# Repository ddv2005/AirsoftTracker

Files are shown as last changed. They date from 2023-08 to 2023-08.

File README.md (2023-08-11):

# AirsoftTracker

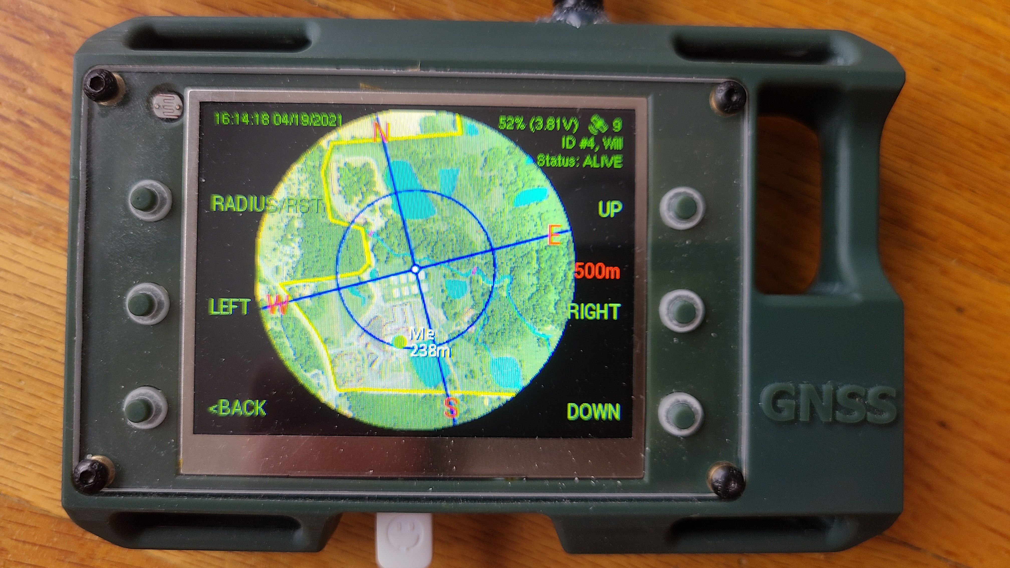
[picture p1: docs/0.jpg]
Airsoft Tracker


Airsoft tracker based on ESP32 with GPS and Lora.
Main features:
- GPS based tracking
- Support basic maps with zoom and rotation
- Lora based communication with P2P
- IMU 9250 for directions
- Current player status
- Timers

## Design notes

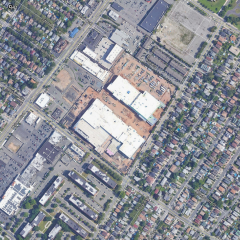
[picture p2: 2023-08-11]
screens/mainscreen/images/0_Converted.png

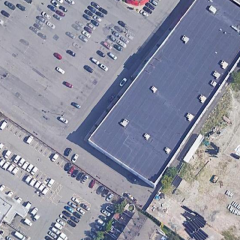
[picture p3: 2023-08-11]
screens/mainscreen/images/Untitled-2_Converted.png

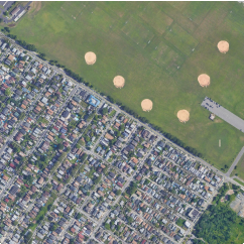
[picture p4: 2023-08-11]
screens/ms2/images/Untitled-2_converted.png

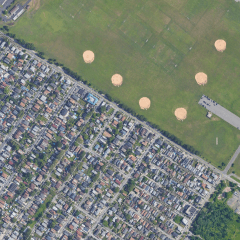
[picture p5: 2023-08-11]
screens/ms2/images/Untitled-2-fs8.png

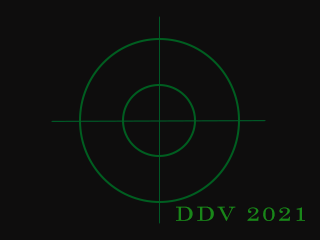
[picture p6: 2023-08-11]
images/at.png

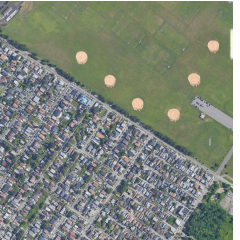
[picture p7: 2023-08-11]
screens/mainscreen/images/Untitled-2-fs8.png

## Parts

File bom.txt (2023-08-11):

1. LILYGO® TTGO T-Beam V1.1 SX1262 LORA 915MHZ ESP32 WiFi Wireless Bluetooth Module GPS NEO-M8N IPEX 18650 $41.85
https://www.aliexpress.com/item/4001287221970.html?spm=a2g0s.9042311.0.0.1f854c4dBQY7TG

2. EVE3-35A-IPS-BLH-TPN-F128 $64.5
https://www.matrixorbital.com/eve3-35a-ips

3. MCP23017 $13
https://www.aliexpress.com/item/32957655097.html?spm=a2g0s.9042311.0.0.1f854c4dBQY7TG

4. SGY-9250 $9 
https://www.aliexpress.com/item/1904051617.html?spm=a2g0s.9042311.0.0.1f854c4dBQY7TG

5. 76342-303LF x2  $2  or      CES-103-01-G-D 
https://www.newark.com/amphenol-icc/76342-303lf/connector-rcpt-6pos-2row-2-54mm/dp/62K8357

6. B3S-1000P x6 $2
https://www.newark.com/omron-electronic-components/b3s-1000p/switch-tactile-spst-no-50ma-smd/dp/50B6363

7. MOLEX 15134-0800 $2.5
https://www.newark.com/molex/15134-0800/cable-assy-8pos-rcpt-rcpt-2/dp/33AC8053

8. MOLEX 53048-0810 $1
https://www.newark.com/molex/53048-0810/connector-header-8pos-1row-1-25mm/dp/98K9836

9. SPC20493 or XG8T-0631 x2 $1
https://www.newark.com/multicomp/spc20493/board-board-connector-header-6way/dp/93K5746
https://www.newark.com/omron-electronic-components/xg8t-0631/connector-header-6-position-2row/dp/05M2064

10. S2B-PH-SM4-TB(LF)(SN)  $0.8
https://www.newark.com/jst-japan-solderless-terminals/s2b-ph-sm4-tb-lf-sn/wire-to-board-connector-header/dp/38K8067

11. GM5539 5mm $0.5
https://www.amazon.com/gp/product/B01N7V536K/ref=ppx_yo_dt_b_search_asin_title?ie=UTF8&psc=1

12. Optional DWM1000 $21
https://www.mouser.com/ProductDetail/772-DWM1000/

13. 10mmx2mm Mini Tiny Vibration Motors 10000rpm Flat Coin Button-Type Micro DC Vibrating Motor $1
https://www.amazon.com/gp/product/B073YFR5WR/ref=ppx_yo_dt_b_search_asin_title?ie=UTF8&psc=1

14. HTSW-150-06-G-S
https://www.digikey.com/en/products/detail/samtec-inc/HTSW-150-06-G-S/8085307

15. Adafruit NPN Bipolar Transistors (PN2222) 
https://www.amazon.com/gp/product/B00XW2OK7M/ref=ppx_yo_dt_b_search_asin_title?ie=UTF8&psc=1

case+hw $10
glass $3
pcb $3

$133/153

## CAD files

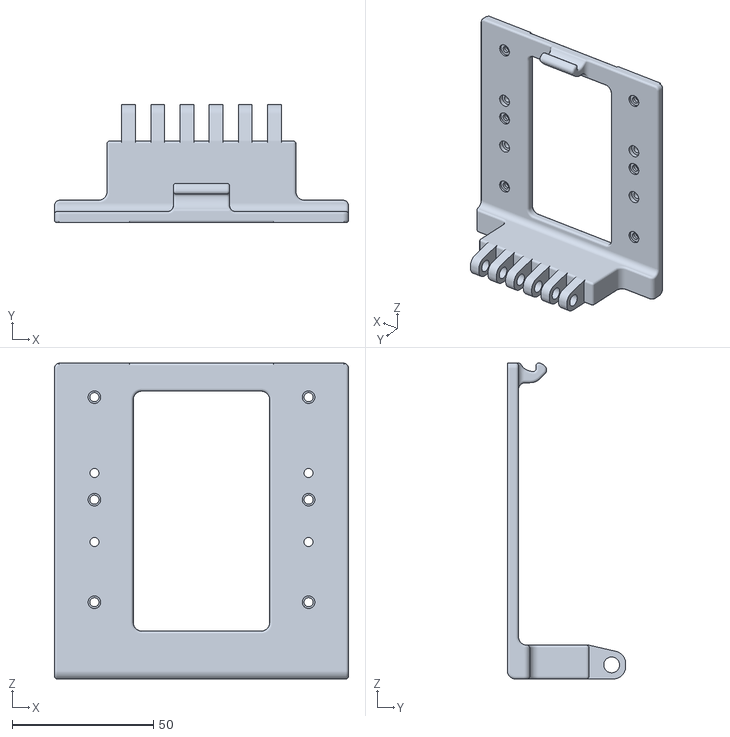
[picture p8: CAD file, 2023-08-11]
cases/holder.stl
104.3 x 42.0 x 112.0

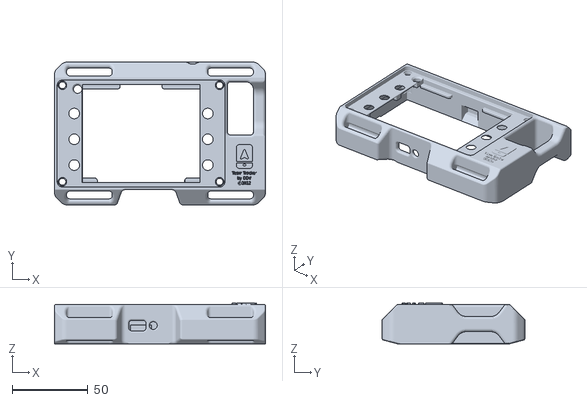
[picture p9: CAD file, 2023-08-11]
cases/airsofttracker.stl
139.0 x 94.0 x 26.8

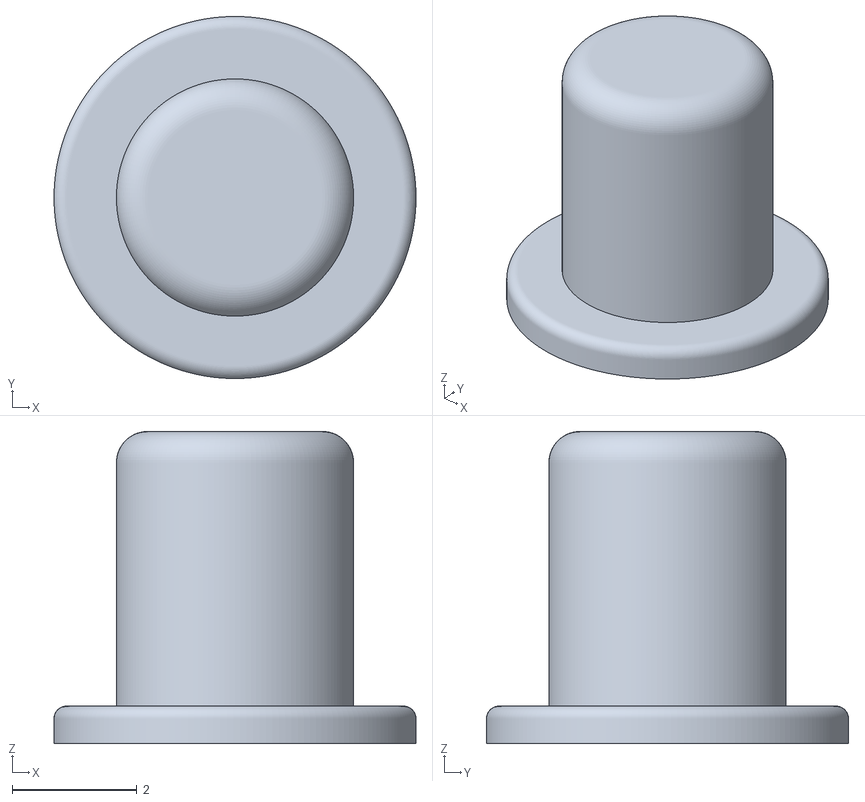
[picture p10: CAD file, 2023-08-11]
cases/at_btn.stl
5.80 x 5.80 x 5.00

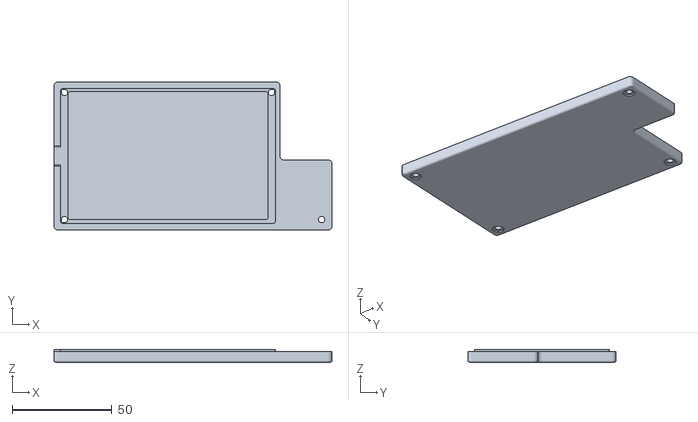
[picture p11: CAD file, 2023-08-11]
cases/at_bottom.stl
139.0 x 74.0 x 6.29

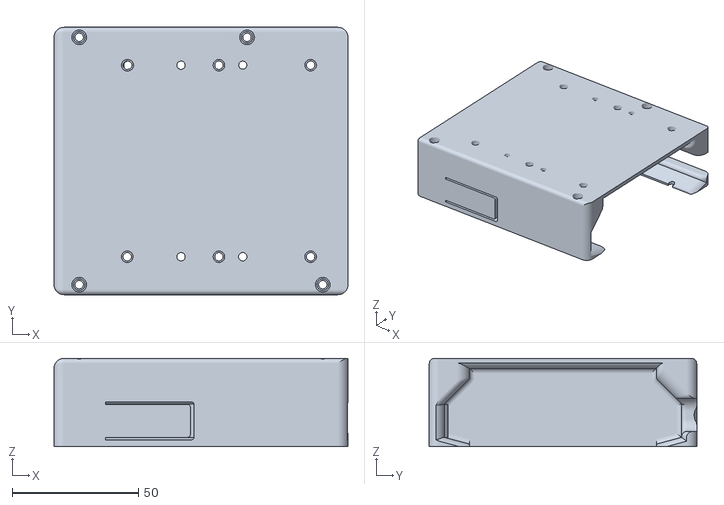
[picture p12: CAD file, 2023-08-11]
cases/atHolster.stl
116.5 x 106.0 x 35.0

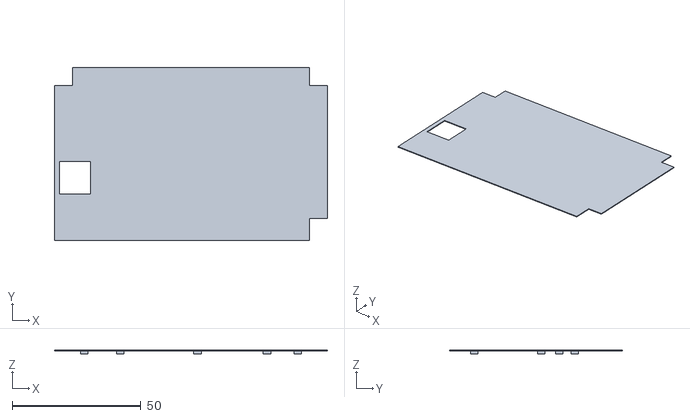
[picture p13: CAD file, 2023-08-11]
cases/at_battery_prot_30.stl
106.0 x 67.0 x 1.51

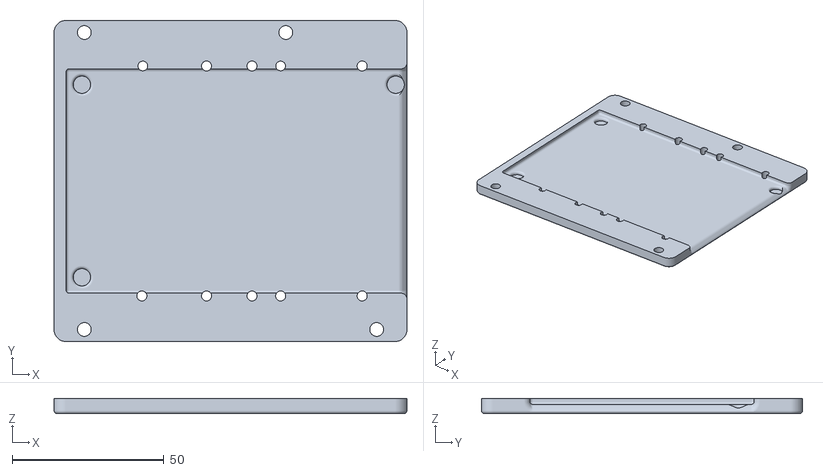
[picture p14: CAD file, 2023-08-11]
cases/atHolsterBack.stl
116.5 x 106.0 x 5.00

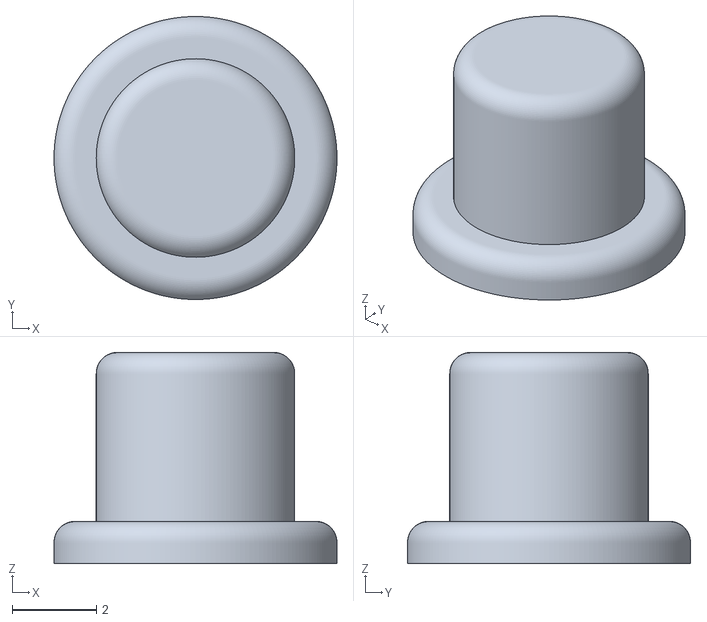
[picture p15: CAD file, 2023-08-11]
cases/at_pwr_btn.stl
6.70 x 6.70 x 5.00

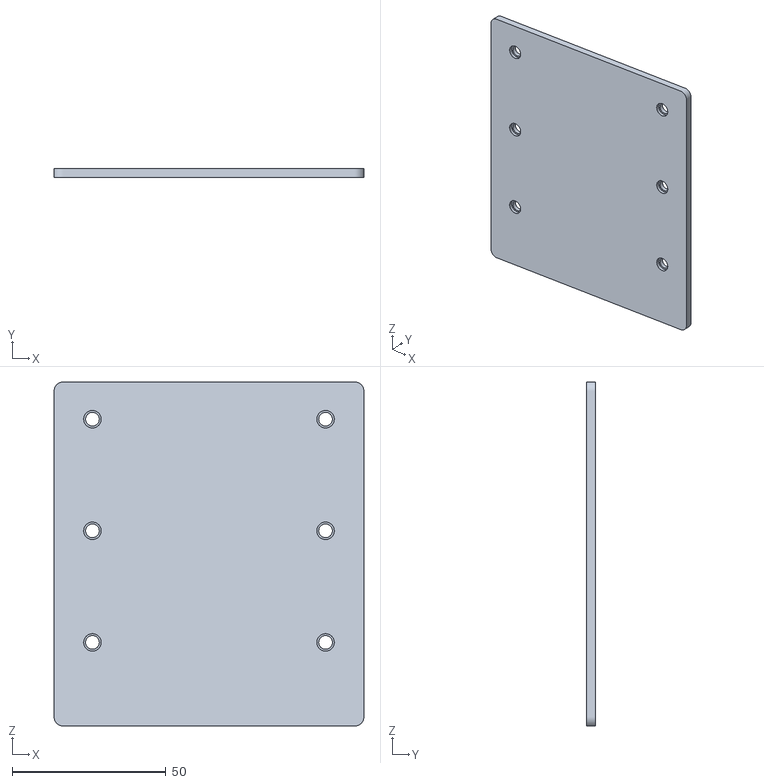
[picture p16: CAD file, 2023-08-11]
cases/holder_plate.stl
100.9 x 3.00 x 112.0

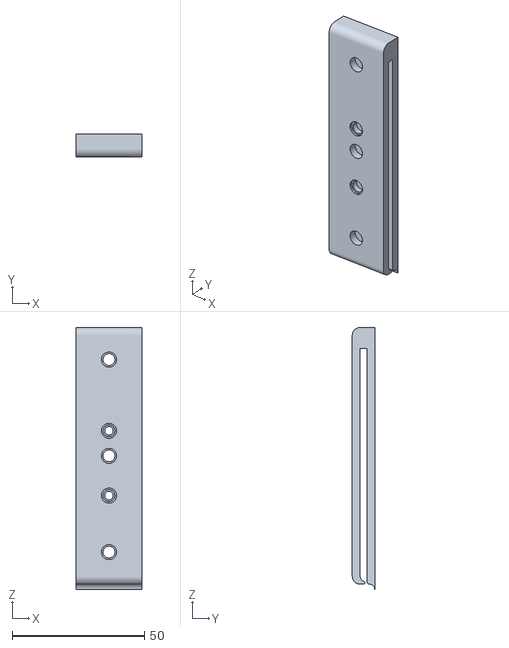
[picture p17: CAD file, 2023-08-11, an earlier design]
cases/holder (2).stl
25.0 x 8.50 x 98.9

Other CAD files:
cases/holder (1).stl

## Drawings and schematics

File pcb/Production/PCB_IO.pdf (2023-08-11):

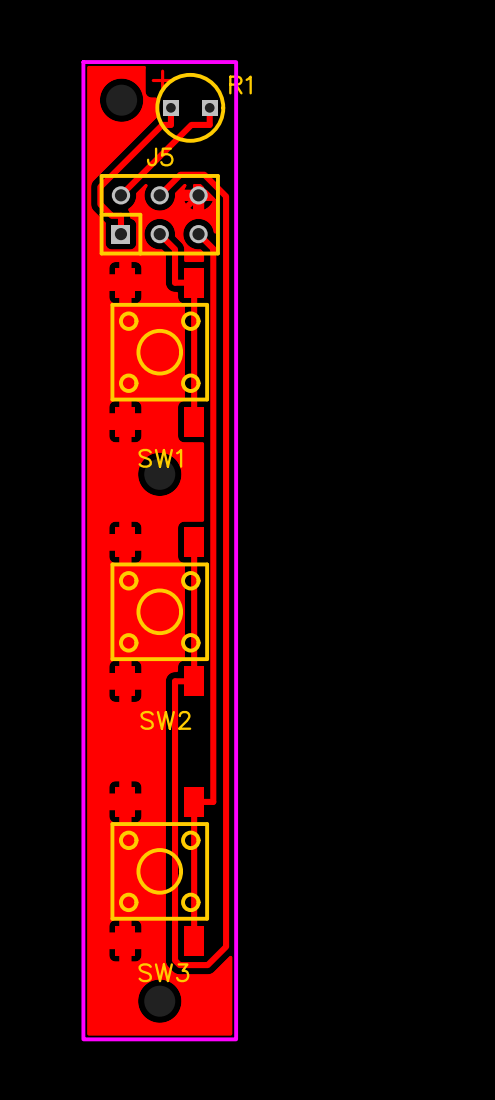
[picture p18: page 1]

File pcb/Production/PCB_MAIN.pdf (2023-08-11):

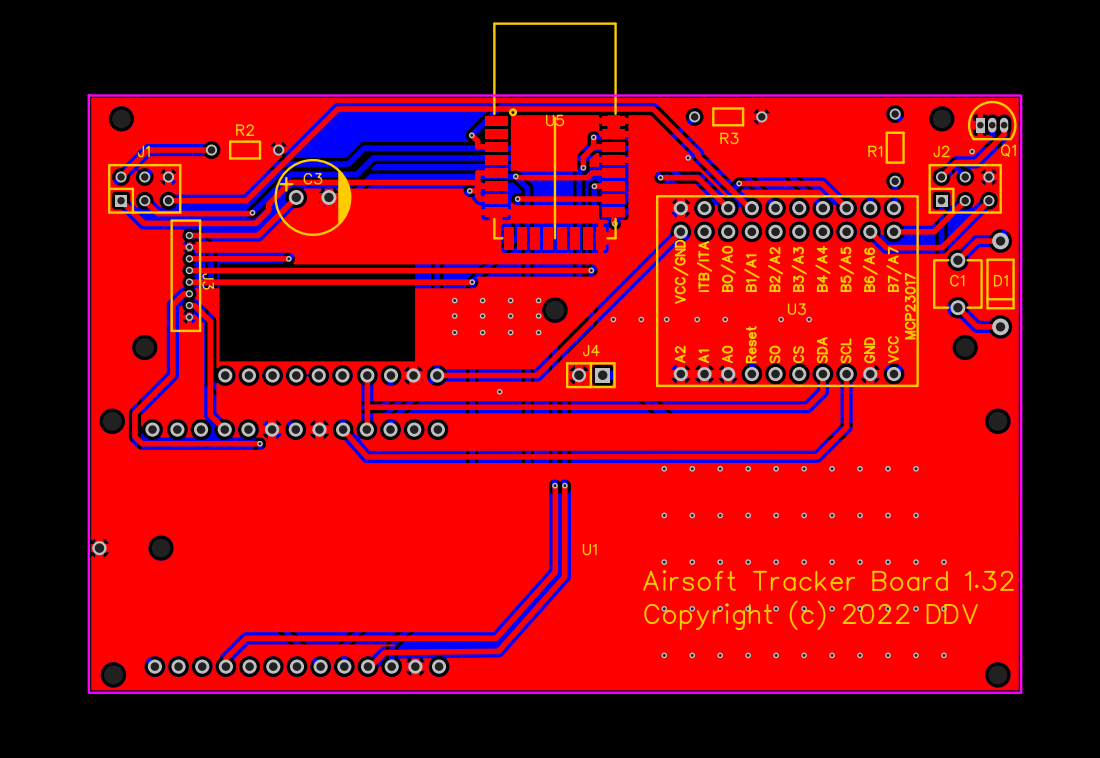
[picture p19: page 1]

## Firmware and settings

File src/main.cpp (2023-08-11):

#include <Arduino.h>
#include <freertos/FreeRTOS.h>
#include <Wire.h>
#include <SPI.h>
#include <SPIFFS.h>
#include <FS.h>
#include "config.h"
#include "global.h"
#include "esp_task_wdt.h"
#include <OneButton.h>
#include "power.h"
#include "atracker.h"
#include <esp_spiffs.h>
#include <EEPROM.h>

cAirsoftTracker *global = NULL;
SemaphoreHandle_t debugLock = xSemaphoreCreateMutex();
void setup() {
    //Hardware init
    esp_bt_controller_mem_release(ESP_BT_MODE_CLASSIC_BT);
#ifdef AD_NOSCREEN    
//    esp_bt_controller_mem_release(ESP_BT_MODE_BTDM);
#endif
    Serial.setRxBufferSize(2048);
    Serial.begin(115200);
    Serial.setDebugOutput(false);
    EEPROM.begin(256);

    FS.begin(true);

    uint32_t seed = esp_random();
    DEBUG_MSG("Setting random seed %u\n", seed);
    randomSeed(seed); // ESP docs say this is fairly random

    DEBUG_MSG("CPU Clock: %d\n", getCpuFrequencyMhz());
    DEBUG_MSG("Total heap: %d\n", ESP.getHeapSize());
    DEBUG_MSG("Free heap: %d\n", ESP.getFreeHeap());
    DEBUG_MSG("Total PSRAM: %d\n", ESP.getPsramSize());
    DEBUG_MSG("Free PSRAM: %d\n", ESP.getFreePsram());


    auto res = esp_task_wdt_init(APP_WATCHDOG_SECS_INIT, true);
    assert(res == ESP_OK);

    res = esp_task_wdt_add(NULL);
    assert(res == ESP_OK);

    esp_vfs_spiffs_conf_t spiffs_1 = {
      .base_path = "/spiffs",
      .partition_label = "spiffs",
      .max_files = 32,
      .format_if_mount_failed = true
    };

    esp_vfs_spiffs_conf_t spiffs_2 = {
      .base_path = "/config",
      .partition_label = "config",
      .max_files = 32,
      .format_if_mount_failed = true
    };  
    SPIFFS.end();
    if(esp_vfs_spiffs_register(&spiffs_1)!=ESP_OK || esp_vfs_spiffs_register(&spiffs_2)!=ESP_OK){
        DEBUG_MSG("An Error has occurred while mounting SPIFFS\n");
    }

    size_t total = 0;
    size_t used = 0;
    if(esp_spiffs_info(spiffs_1.partition_label, &total, &used) == ESP_OK)
    {
        DEBUG_MSG("SPIFFS %s used %d, total %d\n",spiffs_1.partition_label, used, total);
    }
    if(esp_spiffs_info(spiffs_2.partition_label, &total, &used) == ESP_OK)
    {
        DEBUG_MSG("SPIFFS %s used %d, total %d\n",spiffs_2.partition_label, used, total);
    }

    global = new cAirsoftTracker();
    global->init();
    esp_task_wdt_delete(NULL);
}

void loop() 
{
   delay(1000);
}

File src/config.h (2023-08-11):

#ifndef CONFIG_H
#define CONFIG_H

#include <stdint.h>
#include <freertos\FreeRTOS.h>
#include <freertos\semphr.h>

#define ARDUINOJSON_USE_DOUBLE 1

#define DEBUG_PORT Serial // Serial debug port
#ifdef DEBUG_PORT
extern SemaphoreHandle_t debugLock;
#define DEBUG_MSG(...) ({xSemaphoreTake(debugLock, portMAX_DELAY); DEBUG_PORT.printf(__VA_ARGS__); xSemaphoreGive(debugLock);})
#define LOCK_DEBUG_PORT() (xSemaphoreTake(debugLock, portMAX_DELAY))
#define UNLOCK_DEBUG_PORT() (xSemaphoreGive(debugLock))
#else
#define DEBUG_MSG(...)
#define LOCK_DEBUG_PORT()
#define UNLOCK_DEBUG_PORT()
#endif

#define xstr(s) ssstr(s)
#define ssstr(s) #s

//AD_V100 - Lora RF95
//#define AD_V100

//AD_V100 - Lora SX1262
//#define AD_V101

#define APP_WATCHDOG_SECS_INIT 70
#define APP_WATCHDOG_SECS_WORK 15

#define GPS_BAUDRATE 9600
#define GPS_BAUDRATE2 115200
#define GPS_FREQ 2
#define LORA_SEND_LOCATION_PERIOD 10000

#define AC_WIRE Wire1
#define AC_ADDRESS 0x68

#define FLIP_SCREEN_VERTICALLY
#define FS SPIFFS
#define SCK_GPIO 5
#define MISO_GPIO 19
#define MOSI_GPIO 27
#define NSS_GPIO 18 
#define RESET_GPIO 14

#define GPS_SERIAL_NUM 1
#define GPS_RX_PIN 34
#define GPS_TX_PIN 12

#define RF95_IRQ_GPIO 26
#define PMU_IRQ 35
#define SSD1306_ADDRESS 0x3C

#define I2C_SDA 21
#define I2C_SCL 22

#define I2C2_SDA 0
#define I2C2_SCL 4

#define BUTTON_PIN 38     // The middle button GPIO on the T-Beam
#define VIBRO_PIN   7
#define VIBRO_PIN2  3

#define SX1262_E22

#define SX1262_IRQ  33
#define SX1262_RST  23
#define SX1262_BUSY 32
#define SX1262_MAXPOWER 22

#define LORA_BW 500.0
#define LORA_SF 8
#define LORA_CR 7
#define LORA_FREQ 912.0
#define LORA_PRE 8
#define LORA_SYNC 0x64
#define LORA_POWER 17

#define AGD_LORA_BW 125.0
#define AGD_LORA_SF 10
#define AGD_LORA_CR 7
#define AGD_LORA_FREQ 915.0
#define AGD_LORA_PRE 8
#define AGD_LORA_SYNC 0x31

#ifdef AD_V100
#undef  USE_SX1262
#define HAS_AXP20X 1
#define HAS_GPS 1
#endif

#ifdef AD_V101
#define USE_SX1262
#undef  LORA_POWER
#define LORA_POWER SX1262_MAXPOWER
#define HAS_AXP20X 1
#define HAS_GPS 1
#define LORA_CURRENT 140
#endif

#ifdef AD_LORA32_V1
#undef USE_SX1262
#undef PMU_IRQ
#define HAS_GPS
#define AT_CAN_SLEEP
#undef  GPS_FREQ
#define GPS_FREQ 1

#define LORA_SCK 5
#define LORA_MISO 19
#define LORA_MOSI 27
#define LORA_CS 18
#define LORA_RST 14
#define LORA_IRQ 26
#define LORA_CURRENT 240

#define BATTERY_PIN 39
#define LED_PIN -1
#undef  I2C_SCL
#define I2C_SCL 19
#endif

#ifdef  AD_NOSCREEN
#define AD_BLE_NO_CLIENT 
#endif

#define SPI_DISP_SCK    2
#define SPI_DISP_MISO   13
#define SPI_DISP_MOSI   14
#define SPI_DISP_CS     25
#define SPI_DISP_RESET  4

#ifndef AD_NOSCREEN
#define USE_SCREEN_EVE   1
#endif

#define DW1000_IRQ      15
#define DW1000_RST      4
#define DW1000_CS       5

#define PSENSOR_PIN     36

#define BTN1_PIN    0
#define BTN2_PIN    2
#define BTN3_PIN    1
#define BTN4_PIN    15
#define BTN5_PIN    6
#define BTN6_PIN    14

#define SIDE_BUTTONS_COUNT  6

#define GNSS_DBD_FILENAME "/config/gnss.dat"
#define MAIN_CONFIG_FILENAME "/config/main.json"
#define NET_CONFIG_FILENAME "/config/network.json"
#define AGD_NET_CONFIG_FILENAME "/config/agdnet.json"

#define DEFAULT_TZ "EST5EDT,M3.2.0,M11.1.0"

//Packet Prefix
#define  SERIAL_APP_1  0x85
#define  SERIAL_APP_2  0x3B
#define  SERIAL_APP_3  0xDE
#define  SERIAL_APP_4  0x02
#define  MAX_SERIAL_PACKET_SIZE 4200

#define  SERIAL_PROG_MODE_SIG1  0x92
#define  SERIAL_PROG_MODE_SIG2  0x5A

#define  SERIAL_PROG_MODE_RESP  0x07

#define  SERIAL_PROG Serial
#define  SCREEN_FLASH_META_FILE "/spiffs/sflash.json"
#define  SCREEN_FLASH_META_BINARY_FILE "/spiffs/sflash.dat"
#define  SCREEN_FLASH_META_FILE_PATH "/spiffs/"
#define  AT_POINTS_FILE_TEMPLATE "/spiffs/p_%s.json"

#endif
